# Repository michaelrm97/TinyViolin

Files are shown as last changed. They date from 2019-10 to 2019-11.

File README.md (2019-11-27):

# TinyViolin

This project aims to create a small, playable, electric violin. The components of this project are:
- Hardware: PCB design
- Housing: Housing for project, designed to be laser cut with 3mm plywood
- Software:
  * TinyViolin2 - Atmel Studio project which contains the code that runs with the onboard ATMega328 (written in C++ and makes extensive use of Arduino libraries)
  * TVLoader - Visual Studio project which contains code for converting midi files (written in C#)

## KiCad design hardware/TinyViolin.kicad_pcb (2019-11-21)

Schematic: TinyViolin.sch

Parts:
BT1: AAA; 2466; Part Number 2466
C1, C2: 22pF; C_0805_2012Metric_Pad1.15x1.40mm_HandSolder; Part Number CL21C220JBANNNC
C3, C7: 100nF; C_0805_2012Metric_Pad1.15x1.40mm_HandSolder; Part Number CL21B104JBCNNNC
C4, C5, C6: 22uF; C_0805_2012Metric_Pad1.15x1.40mm_HandSolder; Part Number CL21A226MPCLRNC
C10: 100uF; CP_Radial_D6.3mm_P2.50mm; Part Number ECE-A0JKS101
D2: LED; LED_0805_2012Metric_Pad1.15x1.40mm_HandSolder; Part Number LG R971-KN-1
D3, D4, D5, D6: LED; LED_D5.0mm
H1, H2, H3, H4, H5, H6: M3; MountingHole_3.2mm_M3
J1: ICSP; PinHeader_2x03_P2.54mm_Vertical; Part Number M20-9980346
J2: 503182-1852; MOLEX_503182-1852; Part Number 5031821852
L1: 2.2uH; L_1206_3216Metric_Pad1.42x1.75mm_HandSolder; Part Number LQM31PN2R2M00L
LS1: Speaker; SP-1605; Part Number SP-1605
R1: 1M; R_0805_2012Metric_Pad1.15x1.40mm_HandSolder; Part Number RMCF0805FT1M00
R2: 10k; R_0805_2012Metric_Pad1.15x1.40mm_HandSolder; Part Number RNCP0805FTD10K0
R3, R4, R5, R6, R7: 220; R_0805_2012Metric_Pad1.15x1.40mm_HandSolder; Part Number RMCF0805FT220R
RV1: R_POT; PTA4543; Part Number PTA4543-2015DPB103
SW1: SW_SPDT; MHS122; Part Number MHS122
SW2: Tactile; SW_1825910-7; Part Number 1825910-7
SW3, SW4, SW5, SW6: SW_Push; TL1105; Part Number TL1105BF160Q
TP1: VBT; TestPoint_Pad_D1.0mm
TP2: GND; TestPoint_Pad_D1.0mm
TP3: V3.3; TestPoint_Pad_D1.0mm
U1: ATmega328P-PU; DIP-28_W7.62mm_LongPads; Part Number ATMEGA328P-PU
U2: BOOST; SOT95P280X145-5N; Part Number TPS613221ADBVR
Y1: Crystal 8MHz; Crystal_HC49-U_Vertical; Part Number ABL-8.000MHZ-B2

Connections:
+3V3: C3.1, C5.1, C6.1, C7.1, J1.2, J2.4, R2.1, R3.1, RV1.1, TP3.1, U1.7 (VCC), U2.4
/BAT: BT1.1, SW1.1, TP1.1
/BAT1: C4.1, L1.1, SW1.2
/BOW: RV1.2, U1.23 (PC0)
/LED1: R4.1, U1.13 (PD7)
/LED2: R5.1, U1.11 (PD5)
/LED3: R6.1, U1.3 (PD1)
/LED4: R7.1, U1.2 (PD0)
/MISO: J1.1, J2.7, U1.18 (PB4)
/MOSI: J1.4, J2.3, U1.17 (PB3)
/PB1: SW3.1, U1.12 (PD6)
/PB2: SW4.1, U1.6 (PD4)
/PB3: SW5.1, U1.5 (PD3)
/PB4: SW6.1, U1.4 (PD2)
/SCK: J1.3, J2.5, U1.19 (PB5)
/SPEAKER: C10.1, U1.15 (PB1)
/SS: J2.2, U1.16 (PB2)
/VBOOST: L1.2, U2.1
/~RST: J1.5, R2.2, SW2.1, SW2.2, U1.1 (~RESET~/PC6)
GND: BT1.2, C1.2, C2.2, C3.2, C4.2, C5.2, C6.2, C7.2, D2.1, D3.1, D4.1, D5.1, D6.1, J1.6, J2.6, LS1.2, RV1.3, SW2.3, SW2.4, SW3.2, SW4.2, SW5.2, SW6.2, TP2.1, U1.8 (GND), U1.22 (GND), U2.2
unnamed: C1.1, R1.2, U1.10 (XTAL2/PB7), Y1.1
unnamed: C2.1, R1.1, U1.9 (XTAL1/PB6), Y1.2
unnamed: C10.2, LS1.1
unnamed: D2.2, R3.2
unnamed: D3.2, R4.2
unnamed: D4.2, R5.2
unnamed: D5.2, R6.2
unnamed: D6.2, R7.2
unnamed: J2.P1, J2.P2, J2.P3, J2.P4, J2.P5

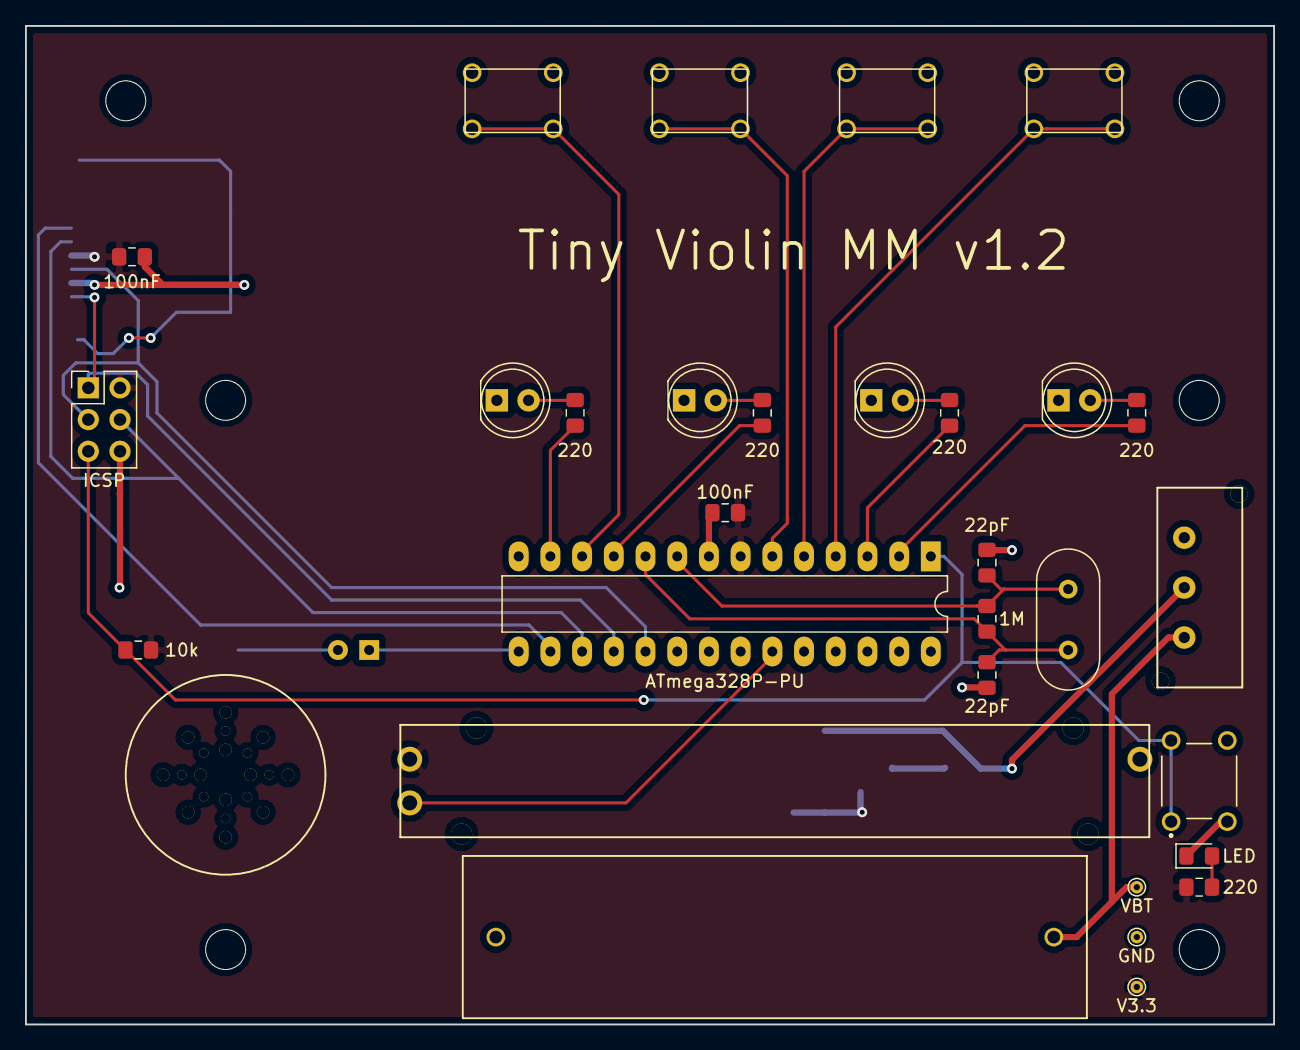
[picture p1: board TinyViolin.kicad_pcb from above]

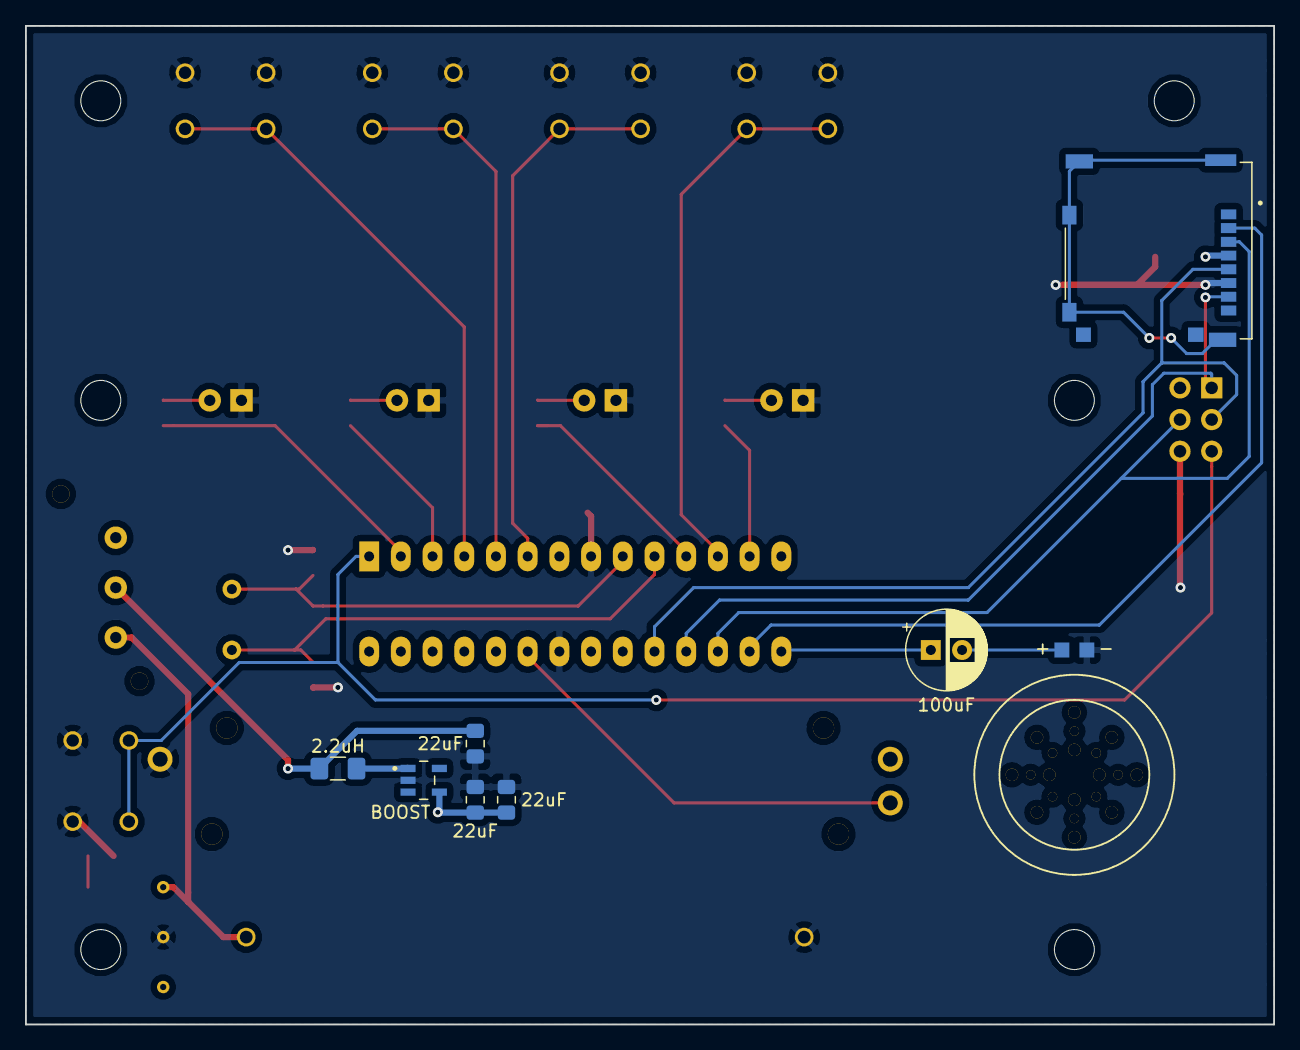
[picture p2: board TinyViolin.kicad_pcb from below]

Board: 2 copper layers, 100.0 x 80.0 mm, 44 parts (8 on the bottom side), 29 nets.

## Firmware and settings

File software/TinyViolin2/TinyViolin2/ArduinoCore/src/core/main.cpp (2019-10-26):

/*
  main.cpp - Main loop for Arduino sketches
  Copyright (c) 2005-2013 Arduino Team.  All right reserved.

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
  You should have received a copy of the GNU Lesser General Public
  License along with this library; if not, write to the Free Software
  Foundation, Inc., 51 Franklin St, Fifth Floor, Boston, MA  02110-1301  USA
*/

#include <Arduino.h>

// Declared weak in Arduino.h to allow user redefinitions.
int atexit(void (* /*func*/ )()) { return 0; }

// Weak empty variant initialization function.
// May be redefined by variant files.
void initVariant() __attribute__((weak));
void initVariant() { }

void setupUSB() __attribute__((weak));
void setupUSB() { }

int main(void)
{
	init();

	initVariant();

#if defined(USBCON)
	USBDevice.attach();
#endif
	
	setup();
    
	for (;;) {
		loop();
		if (serialEventRun) serialEventRun();
	}
        
	return 0;
}

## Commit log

2019-10-17 Created project and started on PCB
    [TinyViolin.kicad_pcb, TinyViolin.sch]
2019-10-17 Changed power supply of LEDs to 5V
    [TinyViolin.sch]
2019-10-18 Updated symbol fields
    [TinyViolin.sch]
2019-10-21 Added all footprints
2019-10-21 Saved pcb
2019-10-26 Designed housing
    [TinyViolin.sch]
2019-10-26 Did pcb
    [_saved_TinyViolin.sch]
2019-10-26 Moved icsp header up
    [TinyViolin.kicad_pcb]
2019-10-26 Fixed labels
    [TinyViolin.kicad_pcb, TinyViolin.sch, _saved_TinyViolin.sch]
2019-10-26 Wrote code for buttons and leds
    [TinyViolin.kicad_pcb, TinyViolin.sch]
2019-10-27 Implemented songs and main interrupt handler
2019-10-27 Moved holes and leds 1mm to the left
    [TinyViolin.kicad_pcb]
2019-10-28 Created dxf file
    [TinyViolin.dxf]
2019-10-30 Converted lines to format needed by laser cutter
    [TinyViolin.dxf]
2019-10-31 Updated pcb for manufacture
    [TinyViolin.kicad_pcb, TinyViolin.sch]
2019-10-31 Added gitignore for Gerber files
2019-11-07 Added colours to leds
2019-11-12 Updated pcb with fixes
    [TinyViolin.kicad_pcb, TinyViolin.sch]
2019-11-12 Connected 3.3V to SD card
    [TinyViolin.kicad_pcb, TinyViolin.sch]
2019-11-13 Updating housing
2019-11-13 Prepared pcb for re-manufacturing
    [TinyViolin.kicad_pcb, TinyViolin.sch]
2019-11-15 Updated code with leds and buttons
2019-11-19 Got main thing working
    [TinyViolin.kicad_pcb, TinyViolin.sch]
2019-11-20 Reduced size of bow pot hole
2019-11-20 Changed battery on PCB
    [TinyViolin.kicad_pcb, TinyViolin.sch]
2019-11-21 Updated components
    [TinyViolin.sch, _saved_TinyViolin.sch]
2019-11-21 Updated PCB and housing for re-re-manufacture
    [TinyViolin.kicad_pcb, TinyViolin.sch, _saved_TinyViolin.sch]
2019-11-26 Added pwm for LED and adjusted pot thresholds
2019-11-26 Fixed leds not turning on on error and release clock speed
2019-11-26 Fixed offsets in certain scales and switching notes
2019-11-26 Reduced brightness of LEDs on error
